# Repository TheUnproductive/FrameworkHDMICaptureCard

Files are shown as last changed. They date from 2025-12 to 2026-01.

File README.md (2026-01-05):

> [!Warning]
>
> Content is not proven and subject to change without notice! Send to fab at your own risk. 

This Project aims to bring a native HDMI Capture Card to the Framework architecture.

The PCB design files can be found inside the ExpansionCards/Electrical/KiCad_templates/Expansion_Card_Retrofit Folder.

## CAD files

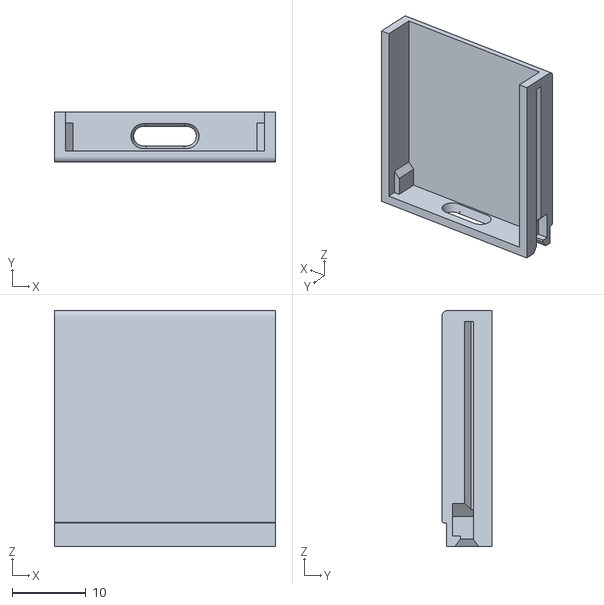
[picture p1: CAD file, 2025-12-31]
ExpansionCards/Mechanical/OpenSCAD/ExpansionCard.stl
30.0 x 6.80 x 32.0

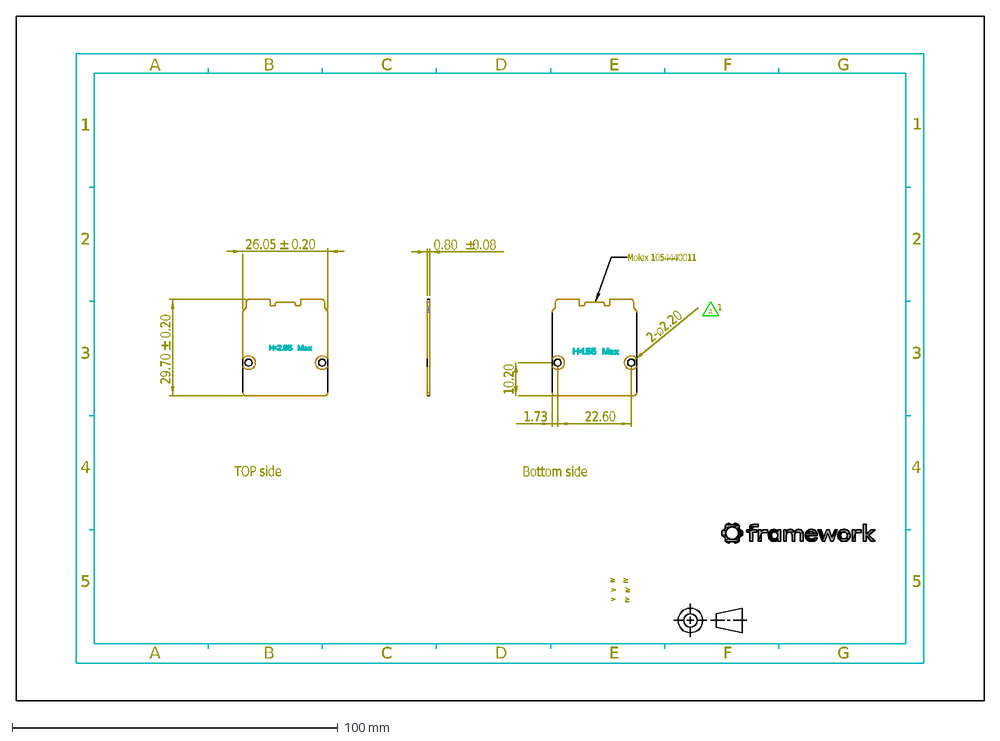
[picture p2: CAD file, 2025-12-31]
ExpansionCards/Mechanical/Printable/2D/ExpansionCard_Printable_M2.dxf
5
4
A
B
C
3
2
1
D
E
F
G
26.05
0.20
29.70
0.80
0.08
10.20
1.73
22.60
TOP side
Bottom side
Molex 1054440011

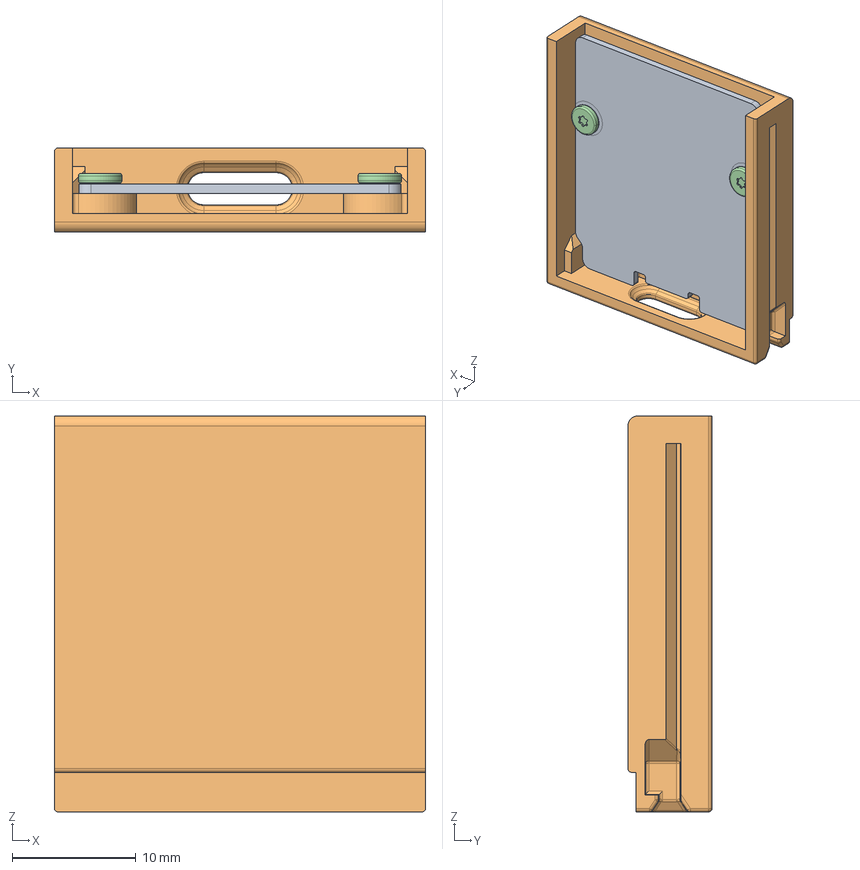
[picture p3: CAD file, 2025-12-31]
ExpansionCards/Mechanical/Printable/3D/ExpansionCard_ThreadedInsert.stp
30.0 x 6.80 x 32.0 mm
FW_EXP_1USBC_FRAME_CLIP_BC_229_
NUT_M2X1-6L_2 x 2
STAR_SCREW_M2X3L_298_2 x 2

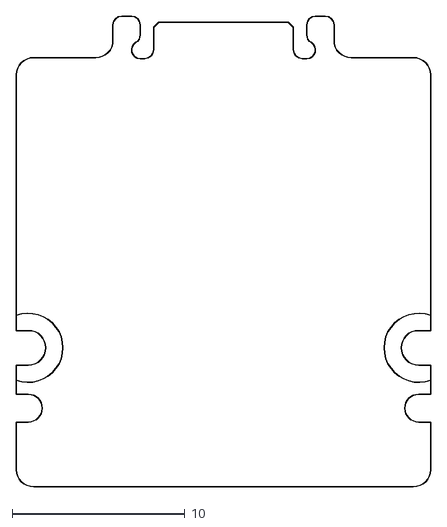
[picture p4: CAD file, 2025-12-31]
ExpansionCards/Mechanical/Retrofit/2D/ExpansionCard_Retrofit_Outline.dxf
24.0 x 27.2

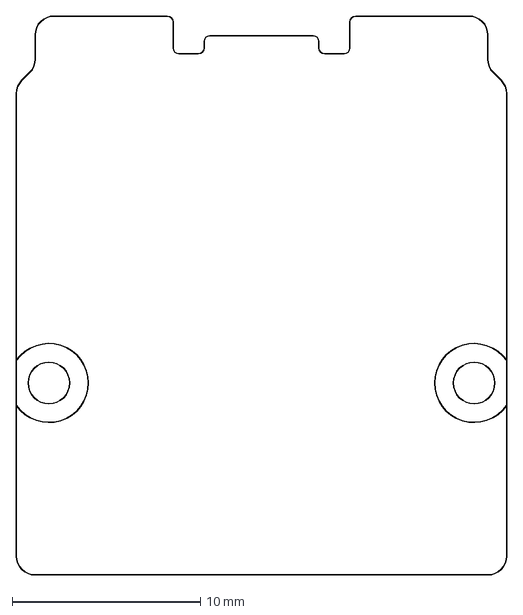
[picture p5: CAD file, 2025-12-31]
ExpansionCards/Mechanical/Printable/2D/ExpansionCard_Printable_Outline.dxf
26.1 x 29.7 mm

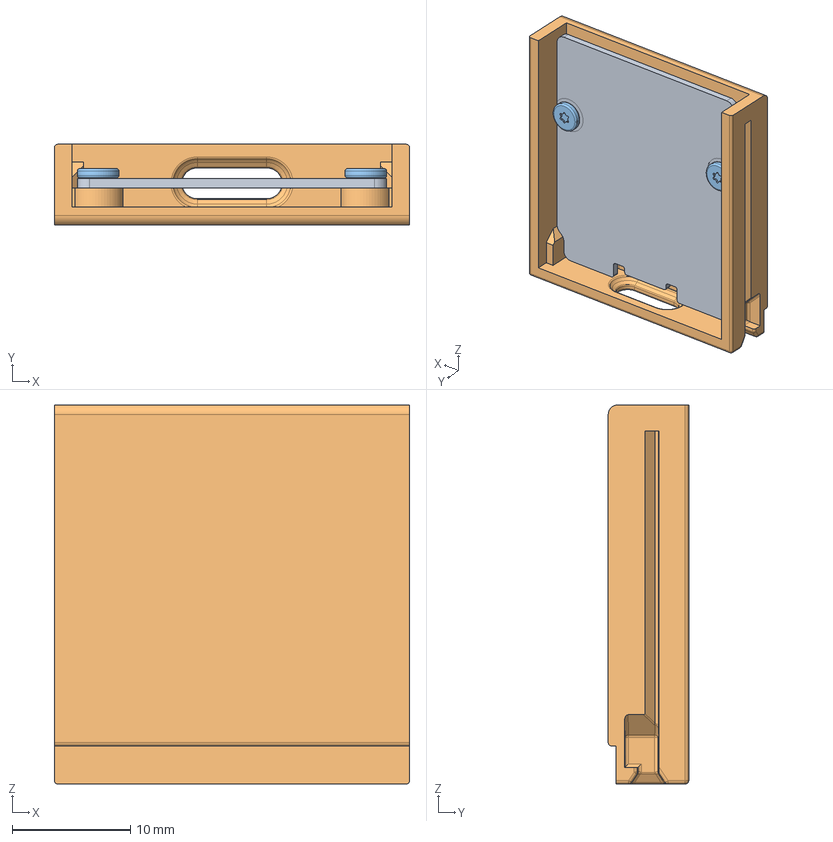
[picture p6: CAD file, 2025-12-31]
ExpansionCards/Mechanical/Printable/3D/ExpansionCard_SelfTapping.stp
30.0 x 6.80 x 32.0 mm
FW_EXP_1USBC_FRAME_CLIP_BC_229_
STAR_SCREW_M2X3L_298_1 x 2

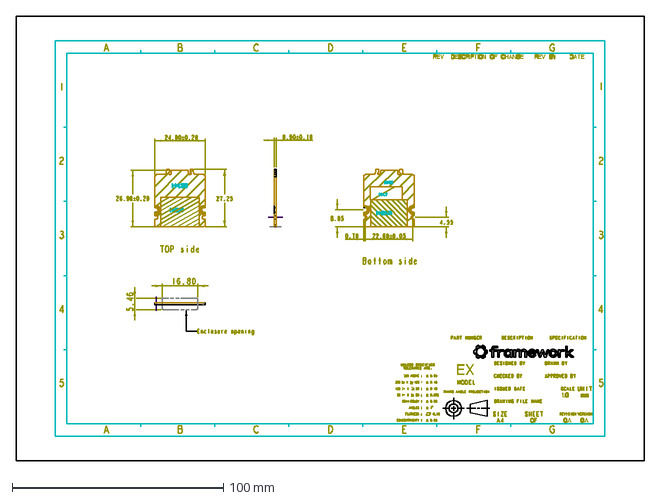
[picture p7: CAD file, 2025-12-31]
ExpansionCards/Mechanical/Retrofit/2D/ExpansionCard_Retrofit.dxf
297.0 x 210.0 mm

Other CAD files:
ExpansionCards/Mechanical/OpenSCAD/MicrocontrollerHousing.stl
ExpansionCards/Mechanical/OpenSCAD/MicrocontrollerHousing.scad
ExpansionCards/Mechanical/OpenSCAD/ExpansionCard.scad
ExpansionCards/Mechanical/Printable/3D/ExpansionCard_SelfTapping.stl
ExpansionCards/Mechanical/Printable/3D/ExpansionCard_ThreadedInsert.stl

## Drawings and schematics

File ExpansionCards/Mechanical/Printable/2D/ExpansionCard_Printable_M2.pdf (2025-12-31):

1

A | B | C

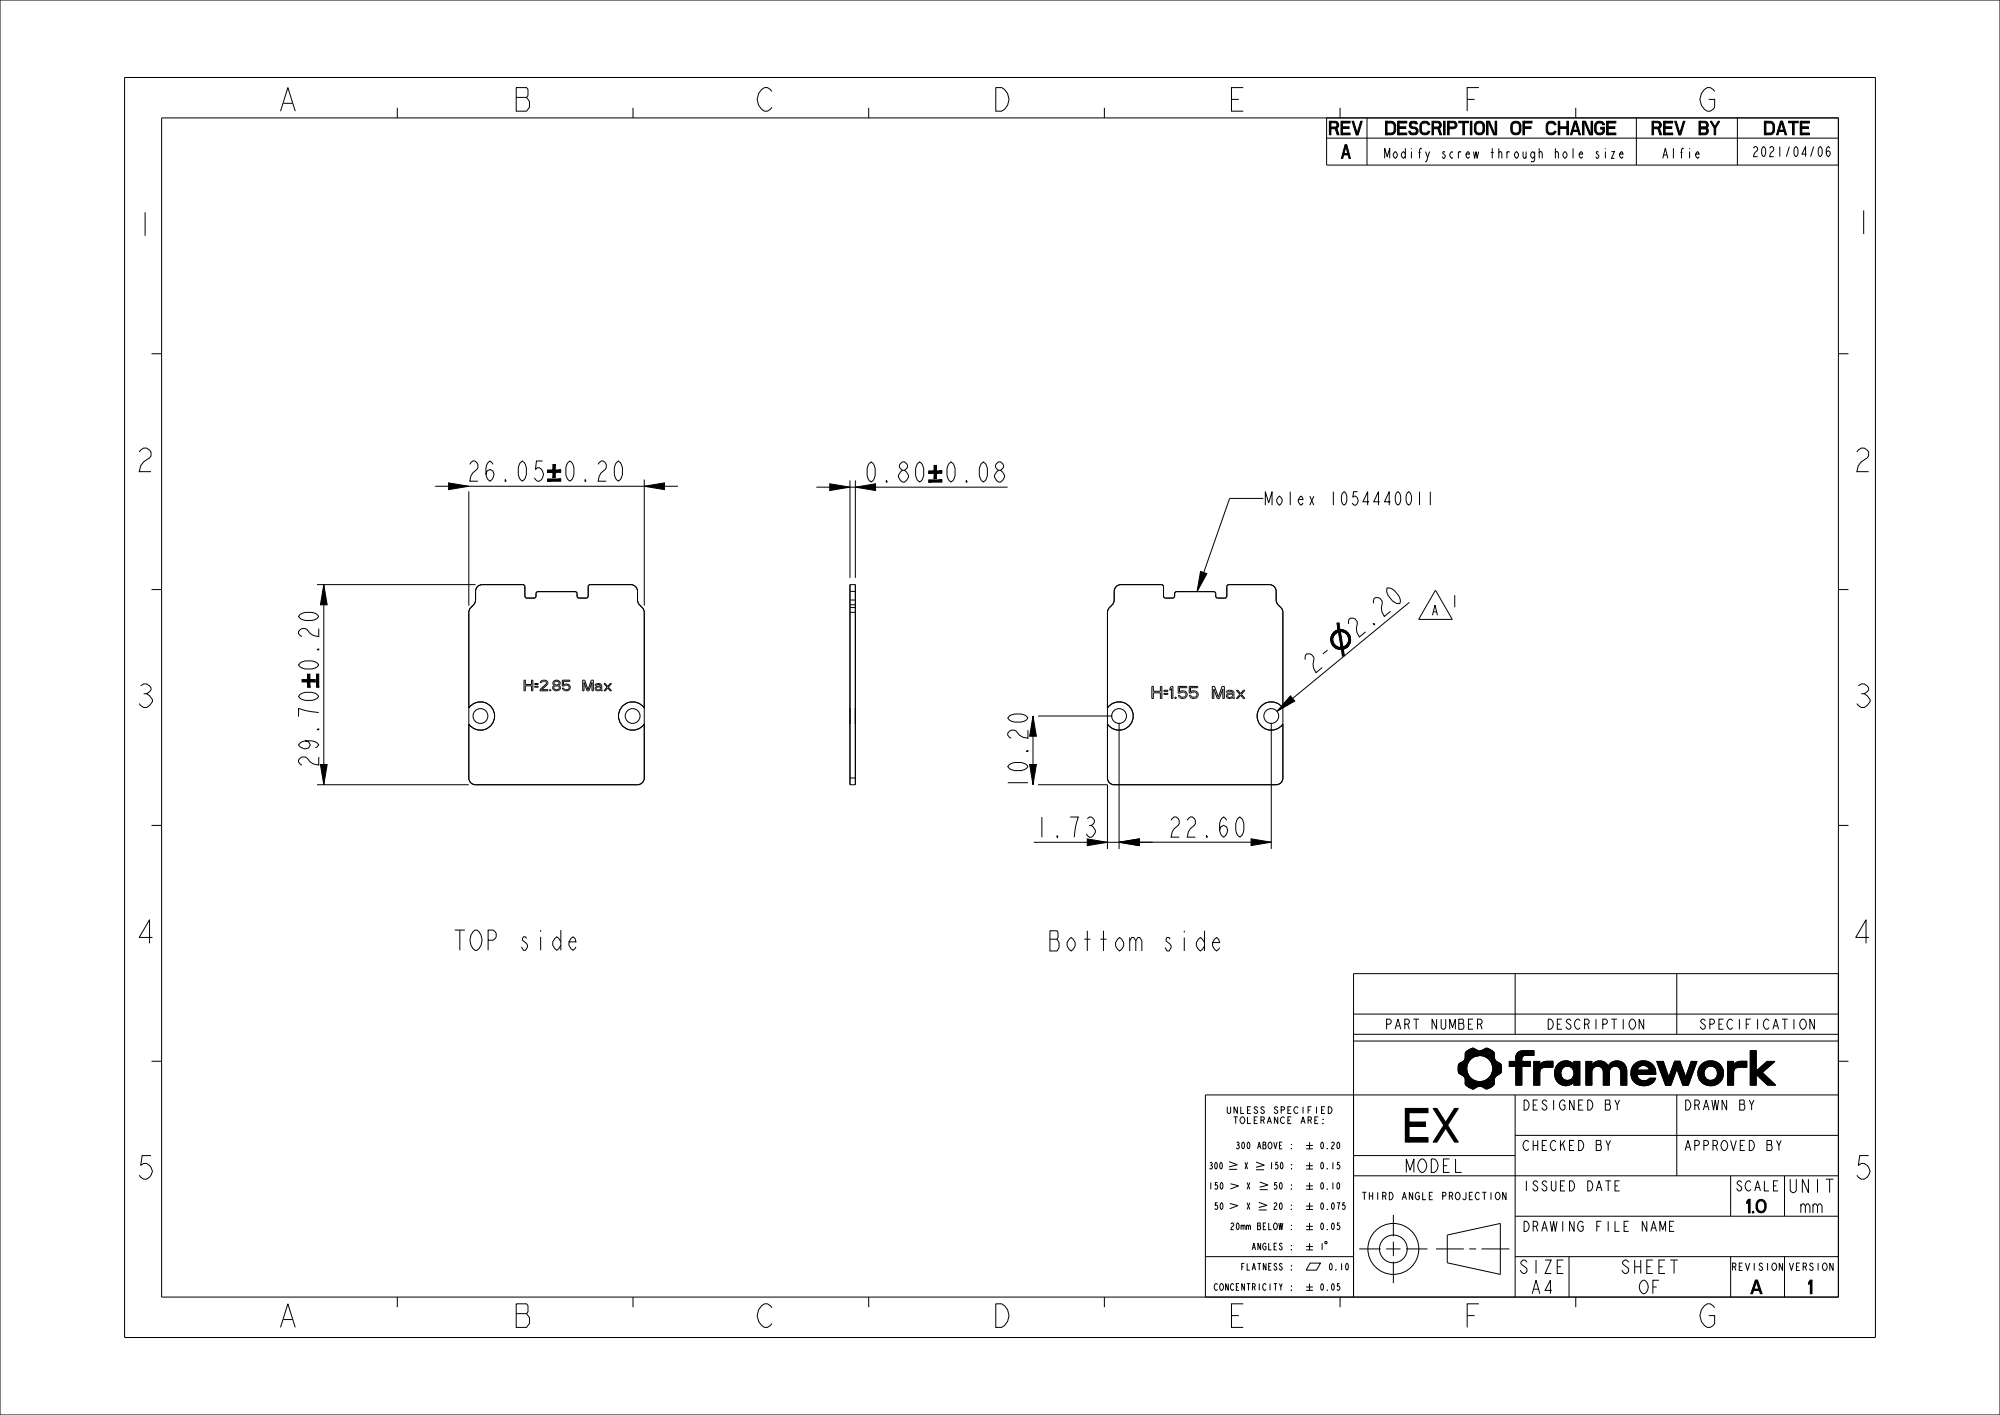
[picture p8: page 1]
PART NUMBER; DESCRIPTION; SPECIFICATION; MODEL; THIRD ANGLE PROJECTION; ISSUED DATE; SCALE UNIT; SIZE; SHEET; REVISION VERSION; REV DESCRIPTION OF CHANGE; REV BY; DATE; Modify screw through hole size; Alfie; FLATNESS :; CONCENTRICITY :; TOP side; Bottom side; Molex 1054440011

UNLESS SPECIFIED TOLERANCE ARE: 300 ABOVE : 300 X 150 : 150 X 50 : 50 X 20 : 20mm BELOW : ANGLES : | EX | DESIGNED BY | DRAWN BY

CHECKED BY | APPROVED BY

DRAWING FILE NAME

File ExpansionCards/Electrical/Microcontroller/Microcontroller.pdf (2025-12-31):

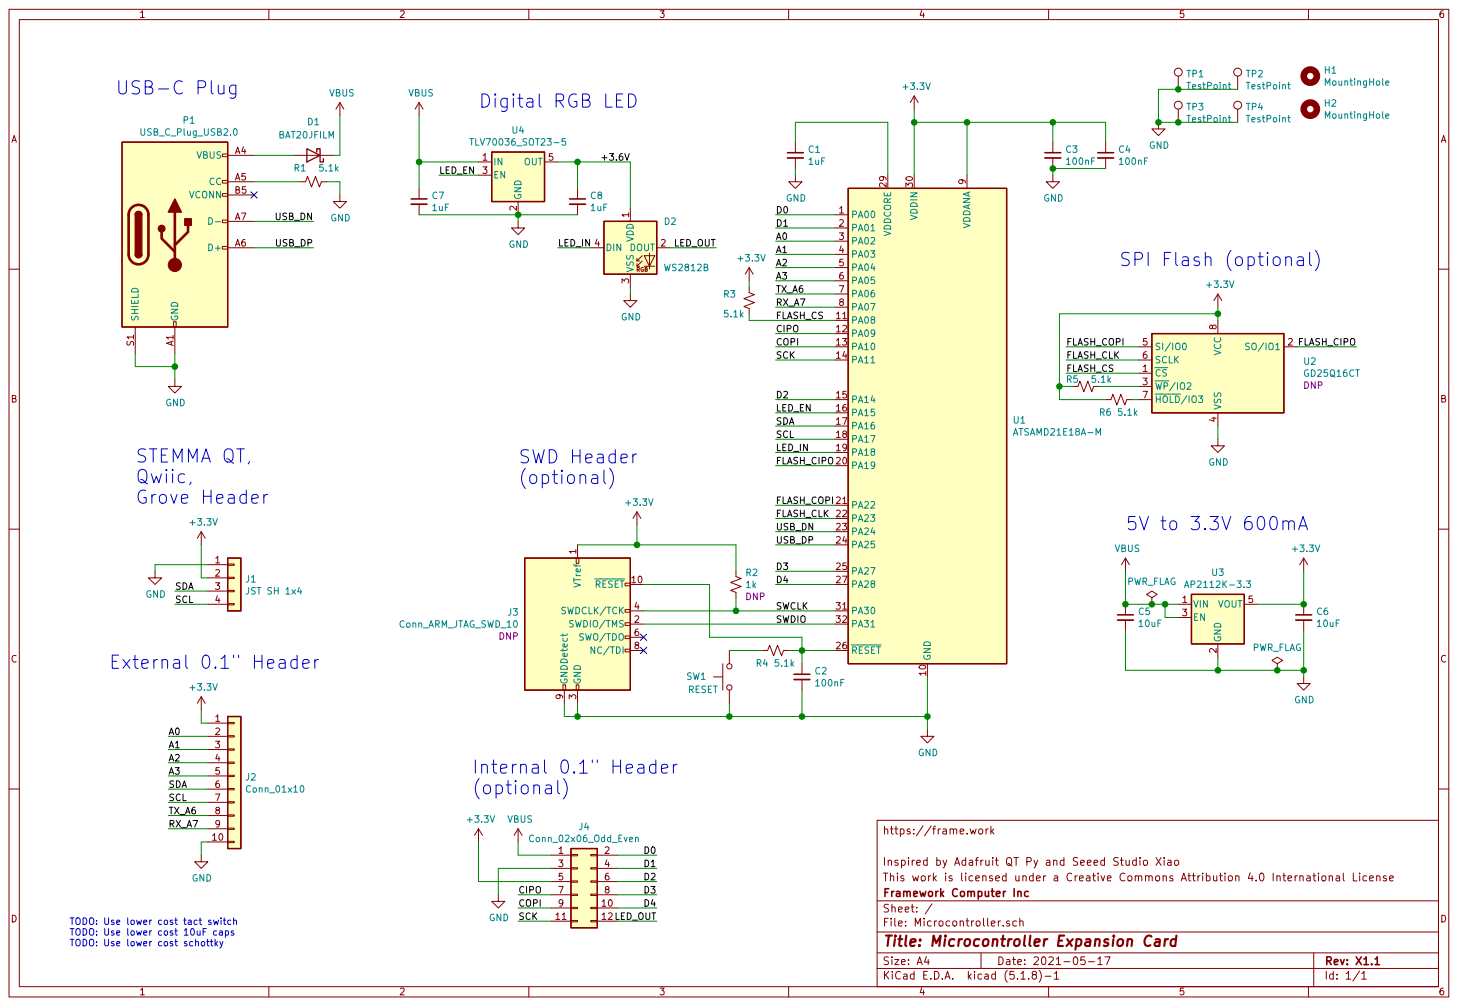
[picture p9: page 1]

3 DIN 4 D2WS2812B GND A1 VBUS A4 CC A5 D+ A6 D- A7 VCONN B5 SHIELD S1 P1 USB_C_Plug_USB2.0 GND

4 SI/IO0 5 SCLK 6 HOLD/IO3 7 VCC

3 SWDCLK/TCK 4 SWO/TDO 6 NC/TDI 8 GNDDetect 9

Inspired by Adafruit QT Py and Seeed Studio Xiao
File: Microcontroller.sch Sheet: / Framework Computer Inc This work is licensed under a Creative Commons Attribution 4.0 International License

7 | 8 D3

TODO: Use lower cost tact switch TODO: Use lower cost 10uF caps

Id: 1/1 Title: Microcontroller Expansion Card

TODO: Use lower cost schottky

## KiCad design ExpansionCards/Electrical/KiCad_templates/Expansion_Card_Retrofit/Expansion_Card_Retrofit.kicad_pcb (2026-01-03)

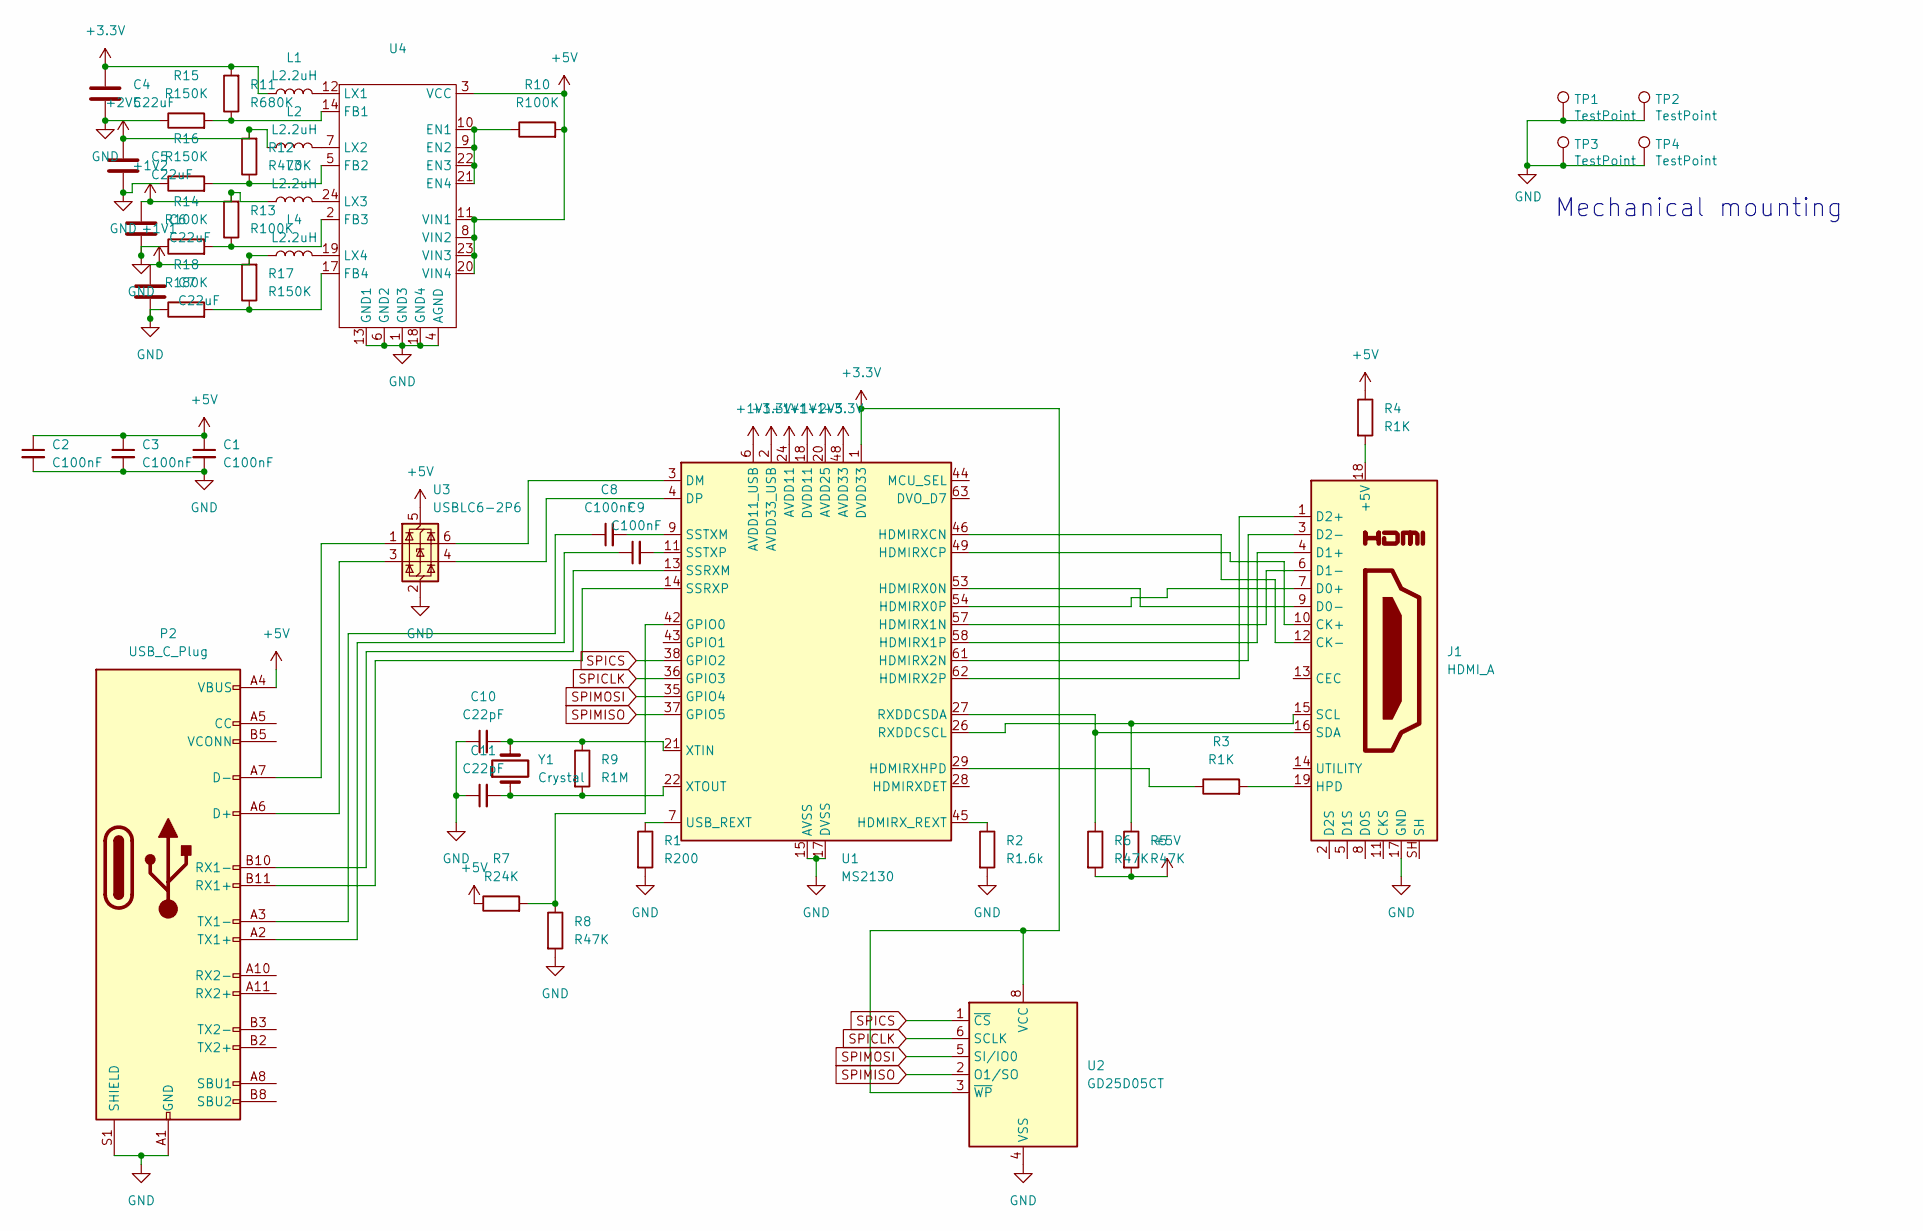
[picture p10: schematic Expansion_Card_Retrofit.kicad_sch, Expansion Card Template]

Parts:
C1, C2, C3, C8, C9: C100nF; C_0201_0603Metric
C4, C5, C6, C7: C22uF; C_0201_0603Metric
C10, C11: C22pF; C_0201_0603Metric
J1: HDMI_A; HDMI_A_Amphenol_10029449-x01xLF_Horizontal
L1, L2, L3, L4: L2.2uH; L_0201_0603Metric
P2: USB_C_Plug; USB_C_Plug_Molex_105444
R1: R200; R_0201_0603Metric
R2: R1.6k; R_0201_0603Metric
R3, R4: R1K; R_0201_0603Metric
R5, R6, R8: R47K; R_0201_0603Metric
R7: R24K; R_0201_0603Metric
R9: R1M; R_0201_0603Metric
R10: R100K; R_0201_0603Metric_Pad0.64x0.40mm_HandSolder
R11: R680K; R_0201_0603Metric
R12: R470K; R_0201_0603Metric
R13, R14: R100K; R_0201_0603Metric
R15, R16, R17: R150K; R_0201_0603Metric
R18: R180K; R_0201_0603Metric
TP1, TP2, TP3, TP4: TestPoint; TestPoint_Pad_1.5x1.5mm
U1: MS2130; QFN-64-1EP_9x9mm_P0.5mm_EP5.7x5.7mm
U2: GD25D05CT; JEITA_SOIC-8_3.9x4.9mm_P1.27mm
U3: USBLC6-2P6; SOT-666
U4: HVQFN-24-1EP_4x4mm_P0.5mm_EP2.1x2.1mm
Y1: Crystal; Crystal_SMD_0603-4Pin_6.0x3.5mm

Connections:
+1V1: C7.1, L4.1, R17.2, U1.6 (AVDD11_USB), U1.10 (AVDD11_USB), U1.12 (AVDD11_USB), U1.18 (DVDD11), U1.24 (AVDD11), U1.39 (DVDD11), U1.51 (AVDD11), U1.55 (AVDD11), U1.59 (AVDD11)
+1V2: C6.1, L3.1, R13.2
+2V5: C5.1, L2.1, R12.2, U1.20 (AVDD25), U1.23 (AVDD25), U1.47 (AVDD25)
+3.3V: C4.1, L1.1, R11.2, U1.1 (DVDD33), U1.2 (AVDD33_USB), U1.5 (AVDD33_USB), U1.8 (AVDD33_USB), U1.16 (DVDD33), U1.31 (DVDD33), U1.33 (DVDD33), U1.41 (DVDD33), U1.48 (AVDD33), U1.52 (AVDD33), U1.56 (AVDD33), U1.60 (AVDD33), U2.3 (~WP), U2.8 (VCC)
+5V: C1.1, C2.1, C3.1, P2.A4 (VBUS), P2.A9 (VBUS), P2.B4 (VBUS), P2.B9 (VBUS), R4.1, R5.2, R6.2, R7.1, R10.2, U3.5 (VBUS), U4.3 (VCC), U4.8 (VIN2), U4.11 (VIN1), U4.20 (VIN4), U4.23 (VIN3)
GND: C1.2, C2.2, C3.2, C4.2, C5.2, C6.2, C7.2, C10.1, C11.1, J1.17 (GND), P2.A1 (GND), P2.A12 (GND), P2.B1 (GND), P2.B12 (GND), P2.S1 (SHIELD), R1.2, R2.2, R8.2, R14.1, R15.1, R16.1, R18.1, TP1.1, TP2.1, TP3.1, TP4.1, U1.15 (AVSS), U1.17 (DVSS), U1.19 (AVSS), U1.25 (AVSS), U1.30 (DVSS), U1.32 (DVSS), U1.34 (DVSS), U1.40 (DVSS), U1.50 (AVSS), U1.64 (DVSS), U1.65 (AVSS), U2.4 (VSS), U3.2 (GND), U4.1 (GND3), U4.4 (AGND), U4.6 (GND2), U4.13 (GND1), U4.18 (GND4)
unnamed: J1.18 (+5V), R4.2
unnamed: J1.10 (CK+), U1.49 (HDMIRXCP)
unnamed: J1.12 (CK-), U1.46 (HDMIRXCN)
unnamed: J1.7 (D0+), U1.54 (HDMIRX0P)
unnamed: J1.9 (D0-), U1.53 (HDMIRX0N)
unnamed: J1.4 (D1+), U1.58 (HDMIRX1P)
unnamed: J1.6 (D1-), U1.57 (HDMIRX1N)
unnamed: J1.1 (D2+), U1.62 (HDMIRX2P)
unnamed: J1.3 (D2-), U1.61 (HDMIRX2N)
unnamed: J1.19 (HPD), R3.2
unnamed: J1.15 (SCL), R5.1, U1.26 (RXDDCSCL)
unnamed: J1.16 (SDA), R6.1, U1.27 (RXDDCSDA)
unnamed: P2.A6 (D+), U3.3 (I/O2)
unnamed: P2.A7 (D-), U3.1 (I/O1)
unnamed: P2.B11 (RX1+), U1.14 (SSRXP)
unnamed: P2.B10 (RX1-), U1.13 (SSRXM)
unnamed: C9.1, P2.A2 (TX1+)
unnamed: C8.1, P2.A3 (TX1-)
unnamed: U1.3 (DM), U3.6 (I/O1)
unnamed: U1.4 (DP), U3.4 (I/O2)
unnamed: R7.2, R8.1, U1.42 (GPIO0)
unnamed: R3.1, U1.29 (HDMIRXHPD)
unnamed: R2.1, U1.45 (HDMIRX_REXT)
unnamed: C8.2, U1.9 (SSTXM)
unnamed: C9.2, U1.11 (SSTXP)
unnamed: R1.1, U1.7 (USB_REXT)
unnamed: C10.2, R9.1, U1.21 (XTIN), Y1.2
unnamed: C11.2, R9.2, U1.22 (XTOUT), Y1.1
unnamed: R10.1, U4.9 (EN2), U4.10 (EN1), U4.21 (EN4), U4.22 (EN3)
unnamed: R11.1, R15.2, U4.14 (FB1)
unnamed: R12.1, R16.2, U4.5 (FB2)
unnamed: R13.1, R14.2, U4.2 (FB3)
unnamed: R17.1, R18.2, U4.17 (FB4)
unnamed: L1.2, U4.12 (LX1)
unnamed: L2.2, U4.7 (LX2)
unnamed: L3.2, U4.24 (LX3)
unnamed: L4.2, U4.19 (LX4)
SPICLK: U1.36 (GPIO3), U2.6 (SCLK)
SPICS: U1.38 (GPIO2), U2.1 (~CS)
SPIMISO: U1.37 (GPIO5), U2.2 (O1/SO)
SPIMOSI: U1.35 (GPIO4), U2.5 (SI/IO0)

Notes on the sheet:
Mechanical mounting

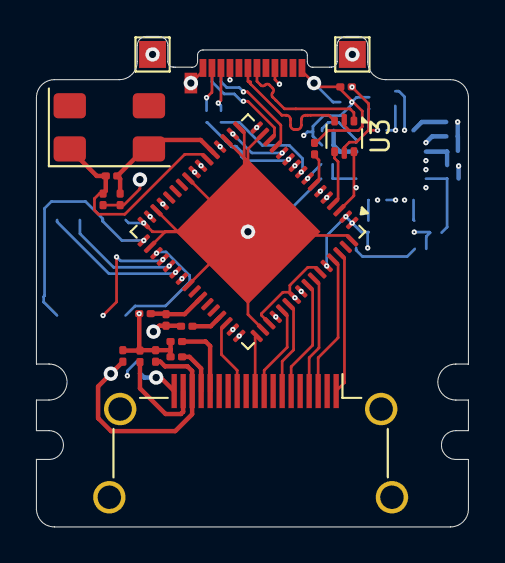
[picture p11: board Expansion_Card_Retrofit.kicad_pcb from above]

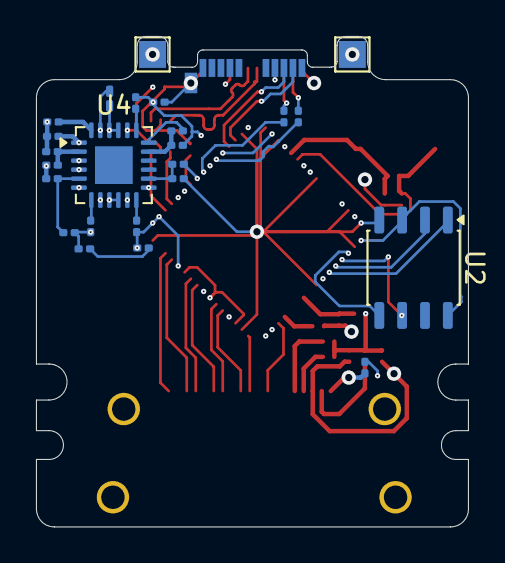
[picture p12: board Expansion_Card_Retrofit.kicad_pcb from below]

Board: 4 copper layers, 24.0 x 27.3 mm, 44 parts (24 on the bottom side), 47 nets.

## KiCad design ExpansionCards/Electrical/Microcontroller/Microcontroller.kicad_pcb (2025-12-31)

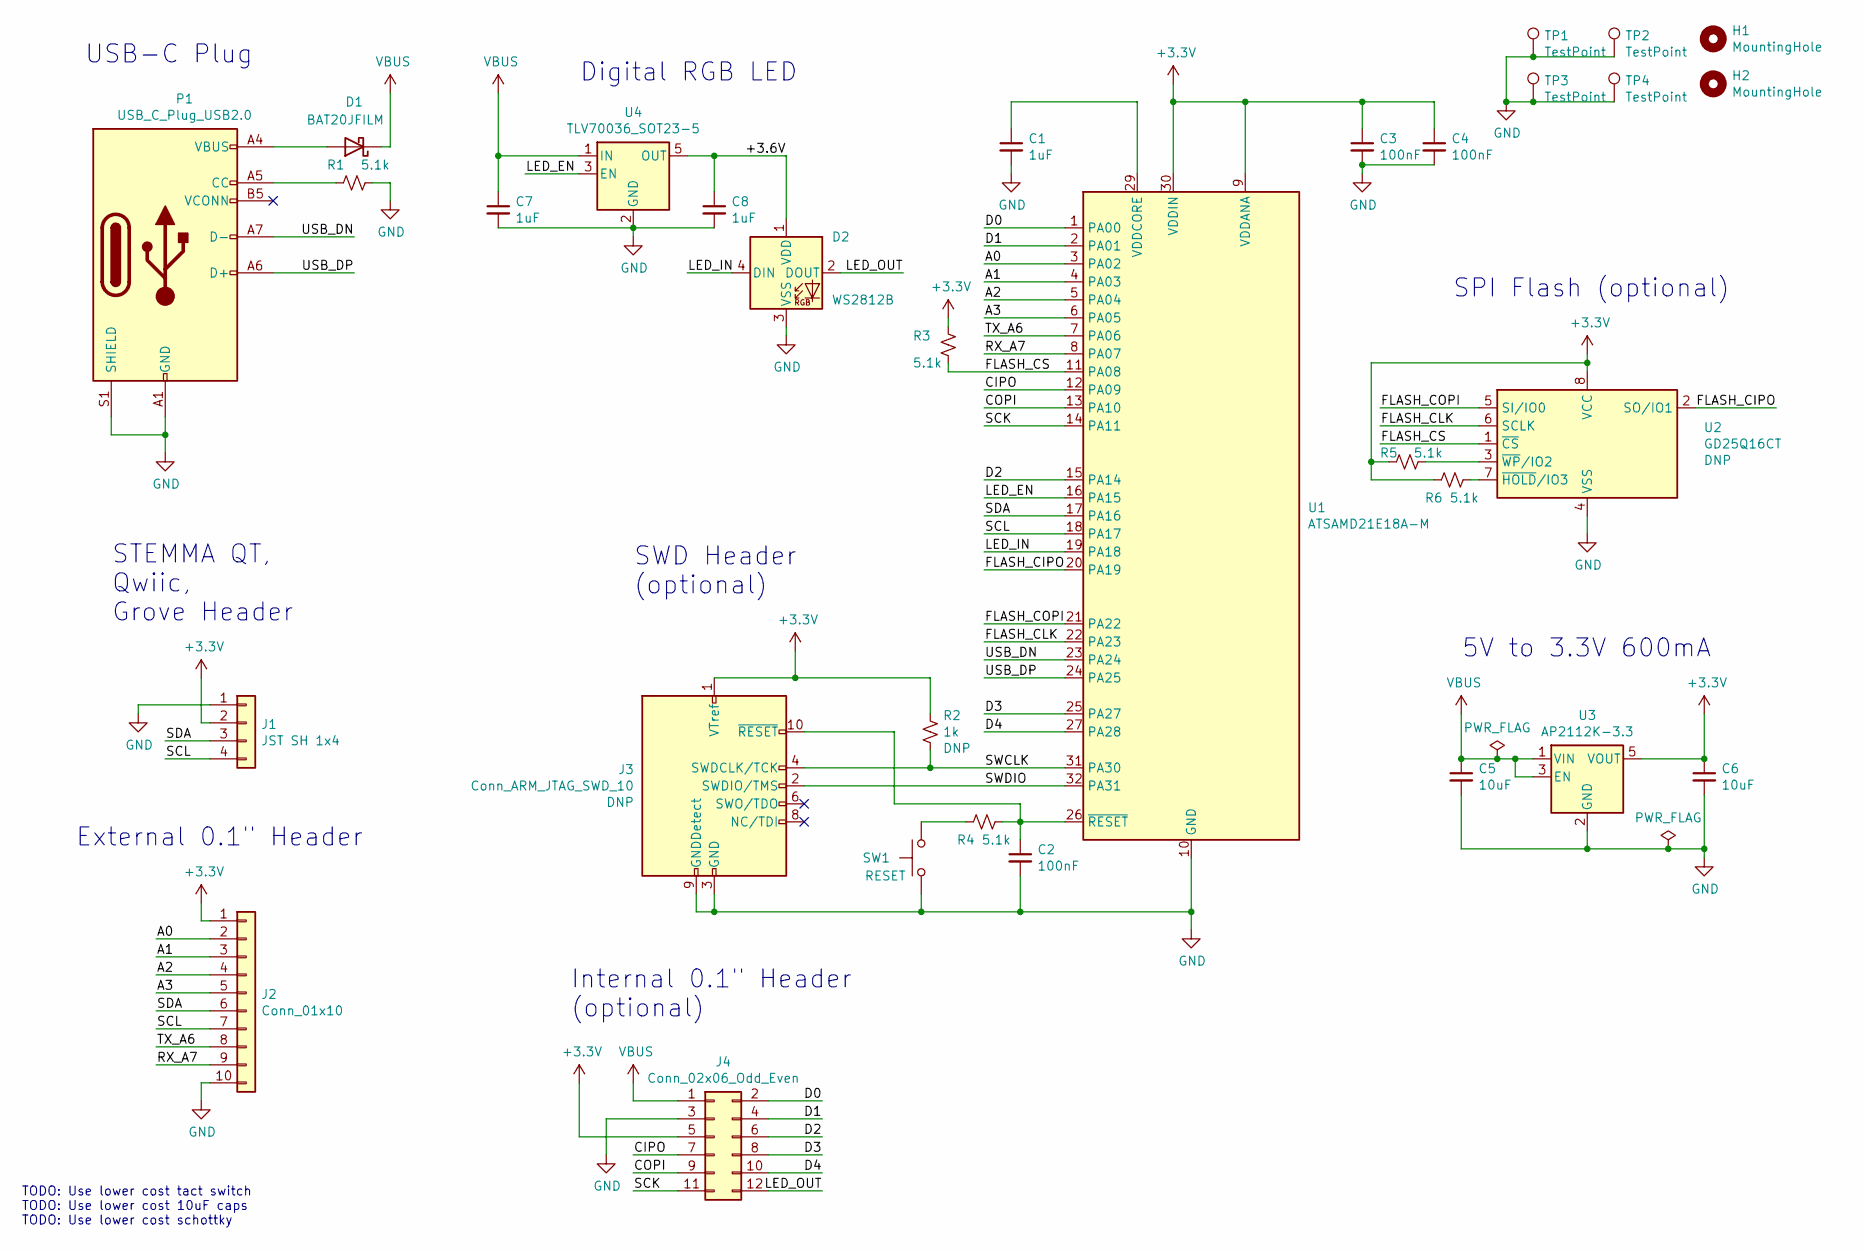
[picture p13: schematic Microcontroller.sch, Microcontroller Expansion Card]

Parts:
C1, C7, C8: 1uF; C_0603_1608Metric
C2, C3, C4: 100nF; C_0603_1608Metric
C5, C6: 10uF; C_0805_2012Metric
D1: BAT20JFILM; D_SOD-323
D2: WS2812B; LED_WS2812B_PLCC4_5.0x5.0mm_P3.2mm
H1, H2: MountingHole; MountingHole_2.2mm_M2
J1: JST SH 1x4; JST_SH_SM04B-SRSS-TB_1x04-1MP_P1.00mm_Horizontal
J2: Conn_01x10; PinSocket_8FM-78-0010-02-146_1x10_P2.54mm_Horizontal_SMD
J3: Conn_ARM_JTAG_SWD_10; PinHeader_2x05_P1.27mm_Vertical_SMD
J4: Conn_02x06_Odd_Even; PinHeader_2x06_P2.54mm_Vertical
P1: USB_C_Plug_USB2.0; USB_C_Plug_Molex_105444
R1, R3, R4, R5, R6: 5.1k; R_0603_1608Metric
R2: 1k; R_0603_1608Metric
SW1: RESET; SW_SPST_B3U-3100P
TP1, TP2, TP3, TP4: TestPoint; TestPoint_Pad_1.5x1.5mm
U1: ATSAMD21E18A-M; QFN-32-1EP_5x5mm_P0.5mm_EP3.6x3.6mm
U2: GD25Q16CT; SOP-8_3.9x4.9mm_P1.27mm
U3: AP2112K-3.3; SOT-23-5
U4: TLV70036_SOT23-5; SOT-23-5

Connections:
+3V3: C3.1, C4.1, C6.1, J1.2, J2.1, J3.1 (VTref), J4.5, R2.1, R3.1, R5.1, R6.1, U1.9 (VDDANA), U1.30 (VDDIN), U2.8 (VCC), U3.5 (VOUT)
/+3.6V: C8.1, D2.1 (VDD), U4.5 (OUT)
/A0: J2.2, U1.3 (PA02)
/A1: J2.3, U1.4 (PA03)
/A2: J2.4, U1.5 (PA04)
/A3: J2.5, U1.6 (PA05)
/CIPO: J4.7, U1.12 (PA09)
/COPI: J4.9, U1.13 (PA10)
/D0: J4.2, U1.1 (PA00)
/D1: J4.4, U1.2 (PA01)
/D2: J4.6, U1.15 (PA14)
/D3: J4.8, U1.25 (PA27)
/D4: J4.10, U1.27 (PA28)
/FLASH_CIPO: U1.20 (PA19), U2.2 (SO/IO1)
/FLASH_CLK: U1.22 (PA23), U2.6 (SCLK)
/FLASH_COPI: U1.21 (PA22), U2.5 (SI/IO0)
/FLASH_CS: R3.2, U1.11 (PA08), U2.1 (~CS)
/LED_EN: U1.16 (PA15), U4.3 (EN)
/LED_IN: D2.4 (DIN), U1.19 (PA18)
/LED_OUT: D2.2 (DOUT), J4.12
/RX_A7: J2.9, U1.8 (PA07)
/SCK: J4.11, U1.14 (PA11)
/SCL: J1.4, J2.7, U1.18 (PA17)
/SDA: J1.3, J2.6, U1.17 (PA16)
/SWCLK: J3.4 (SWDCLK/TCK), R2.2, U1.31 (PA30)
/SWDIO: J3.2 (SWDIO/TMS), U1.32 (PA31)
/TX_A6: J2.8, U1.7 (PA06)
/USB_DN: P1.A7 (D-), U1.23 (PA24)
/USB_DP: P1.A6 (D+), U1.24 (PA25)
GND: C1.2, C2.2, C3.2, C4.2, C5.2, C6.2, C7.2, C8.2, D2.3 (VSS), J1.1, J2.10, J3.3 (GND), J3.5 (GND), J3.9 (GNDDetect), J4.3, P1.A1 (GND), P1.A12 (GND), P1.B1 (GND), P1.B12 (GND), P1.S1 (SHIELD), R1.2, SW1.1, TP1.1, TP2.1, TP3.1, TP4.1, U1.10 (GND), U1.28 (GND), U1.33 (EP), U2.4 (VSS), U3.2 (GND), U4.2 (GND)
unnamed: C1.1, U1.29 (VDDCORE)
unnamed: C2.1, J3.10 (~RESET~), R4.2, U1.26 (~RESET)
unnamed: D1.2 (A), P1.A4 (VBUS), P1.A9 (VBUS), P1.B4 (VBUS), P1.B9 (VBUS)
unnamed: P1.A5 (CC), R1.1
unnamed: R4.1, SW1.2
unnamed: R5.2, U2.3 (~WP~/IO2)
unnamed: R6.2, U2.7 (~HOLD~/IO3)
VBUS: C5.1, C7.1, D1.1 (K), J4.1, U3.1 (VIN), U3.3 (EN), U4.1 (IN)

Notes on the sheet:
TODO: Use lower cost tact switch TODO: Use lower cost 10uF caps TODO: Use lower cost schottky
5V to 3.3V 600mA
SPI Flash (optional)
USB-C Plug
Digital RGB LED
STEMMA QT, Qwiic, Grove Header
SWD Header (optional)
External 0.1" Header
Internal 0.1" Header (optional)

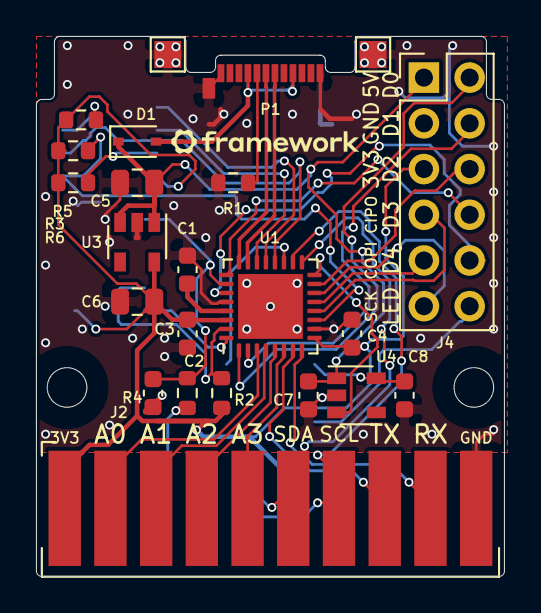
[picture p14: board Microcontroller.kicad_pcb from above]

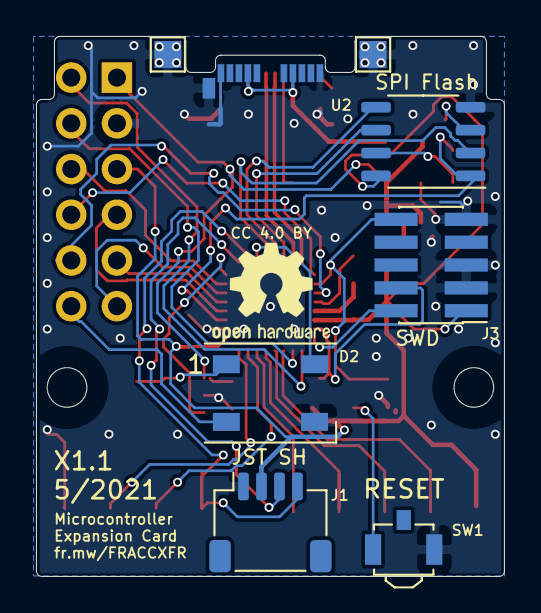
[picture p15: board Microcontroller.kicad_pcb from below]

Board: 2 copper layers, 26.0 x 30.0 mm, 32 parts (7 on the bottom side), 38 nets.

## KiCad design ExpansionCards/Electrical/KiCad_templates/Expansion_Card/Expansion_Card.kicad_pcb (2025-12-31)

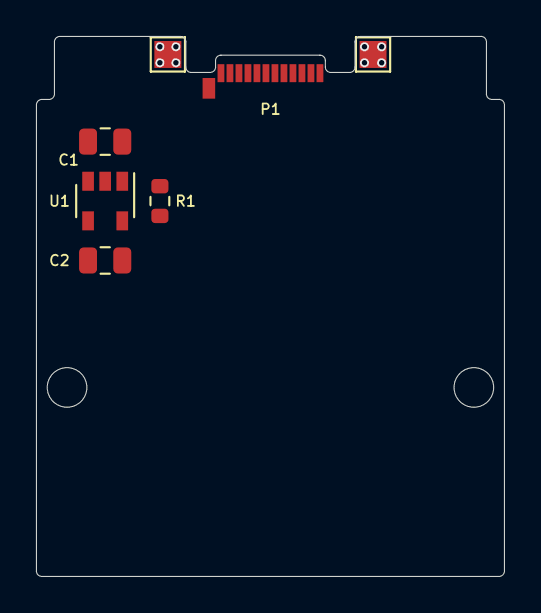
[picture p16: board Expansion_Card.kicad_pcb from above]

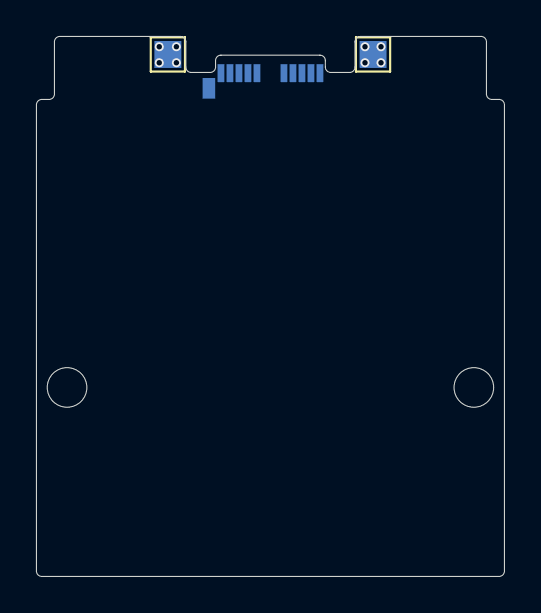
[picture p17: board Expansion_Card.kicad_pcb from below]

Board: 2 copper layers, 26.0 x 30.0 mm, 11 parts (2 on the bottom side), 4 nets, no tracks yet.

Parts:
C1, C2: 10uF; C_0805_2012Metric
H1, H2: MountingHole; MountingHole_2.2mm_M2
P1: USB_C_Plug_USB2.0; USB_C_Plug_Molex_105444
R1: 5.1k; R_0603_1608Metric
TP1, TP2, TP3, TP4: TestPoint; TestPoint_Pad_1.5x1.5mm
U1: AP2112K-3.3; SOT-23-5

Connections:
+3V3: C2.1, U1.5
GND: C1.2, C2.2, P1.A1, P1.A12, P1.B1, P1.B12, P1.S1, R1.2, TP1.1, TP2.1, TP3.1, TP4.1, U1.2
unnamed: P1.A5, R1.1
VBUS: C1.1, P1.A4, P1.A9, P1.B4, P1.B9, U1.1, U1.3

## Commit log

2025-12-31 Add initial files
    [ExpansionCard.scad, ExpansionCard.stl, ExpansionCard_Printable_M2.dxf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]
2026-01-02 Change PCB to 4 Layer and improve routing
    [Expansion_Card_Retrofit.kicad_pcb, Expansion_Card_Retrofit.kicad_sch]
2026-01-02 Prepare for gerber export
    [Expansion_Card_Retrofit.kicad_pcb]
2026-01-02 Add project description and PCB design location
2026-01-02 Finished PCB design and add gerber files and BOM
    [Expansion_Card_Retrofit-B_Cu.gbr, Expansion_Card_Retrofit-B_Mask.gbr, Expansion_Card_Retrofit-B_Silkscreen.gbr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]
2026-01-03 Modified the USB traces to get more closely matching trace lengths
    [Expansion_Card_Retrofit.kicad_pcb]
